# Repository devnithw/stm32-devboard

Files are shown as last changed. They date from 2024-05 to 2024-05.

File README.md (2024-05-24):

# STM32 Development board

This project contains KiCAD project files for a custom STM32 development board PCB which uses the STM32F103C8Tx microcontroller.

## Schematic design
The PCB schematic file for development board is contained in the file `stm32_board.kicad_sch`. The following is a screenshot of the schematic. 

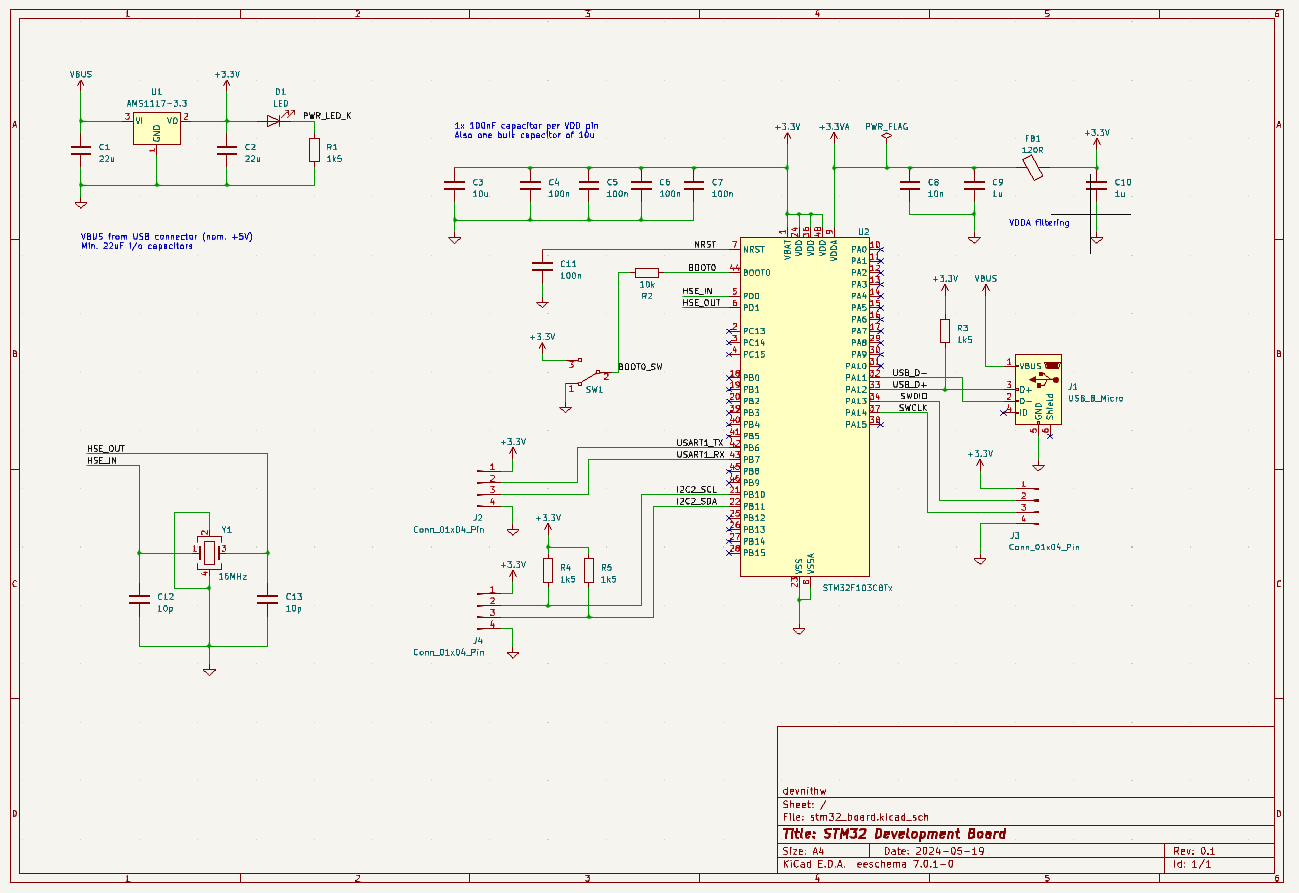
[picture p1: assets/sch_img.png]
Schematic


The development board uses the `STM32F103C8Tx` microcontroller. USB interface is used for both power supply and serial communication. The power fdrom the USB interface is regulated to +3.3V using the regulator circuit. An High Speed External clock is used for 16 MHz operation. The board includes pin header ports for UART and I2C communication also.

## PCB design
The PCB layout file for the circuit is contained in `stm32_board.kicad_pcb` file. Below is the screenshot of the final PCB layout after routing. I have included mounting holes for the board to be mounted onto a enclosure. The footprints for most of the components have been used from the KiCAD library itself. 3D view for the USB port was downloaded from the manufaturer's website as a step file. It is included in the file `629105150521 (rev1).stp`. I have added male headers for the UART, Serial Wire Debug and I2C communication ports. These can be configured using the STM32 Cube IDE software. 

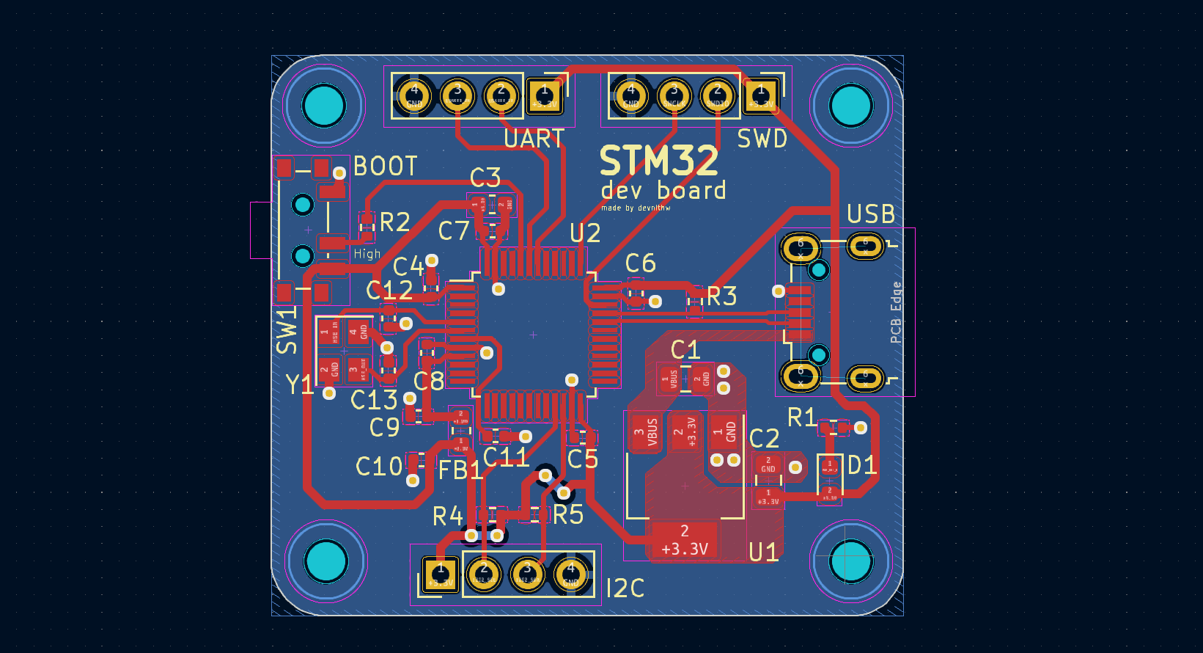
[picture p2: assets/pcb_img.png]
PCB


Shown below is the 3D view of the routed and finalized PCB.

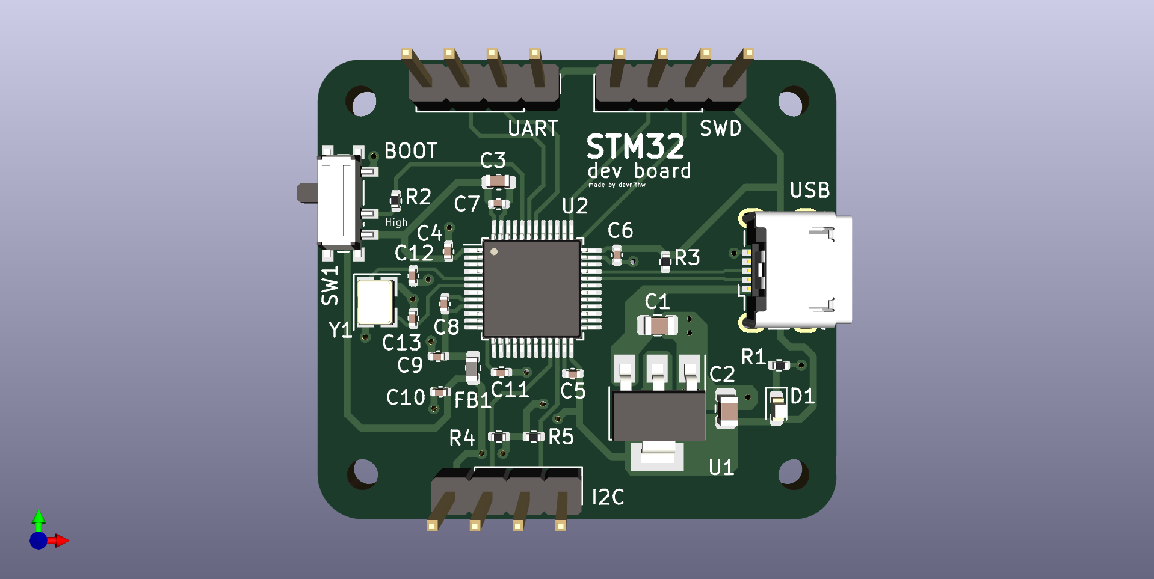
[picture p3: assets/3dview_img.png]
3DView


This project was done following the Udemy course by Philip Salmony. [Reference](https://www.udemy.com/course/learn-kicad-v6-and-stm32-hardware-design/)

## Technologies Used
- KiCAD V7
- STM32

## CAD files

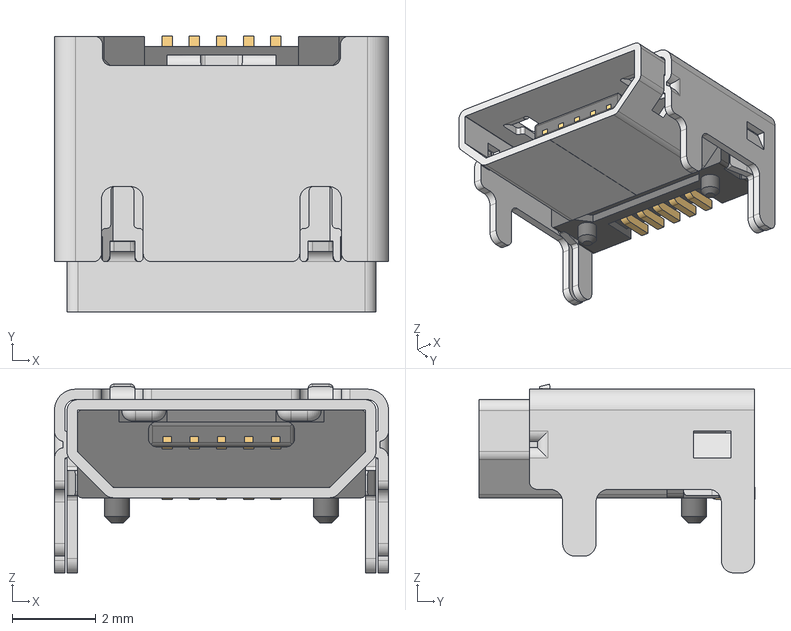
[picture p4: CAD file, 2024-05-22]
629105150521 (rev1).stp
8.00 x 6.60 x 4.52 mm
629105150521_Housing
629105150521_Pin1 x 4
629105150521_Pin2
629105150521_Shielding2
629105150521_Shielding

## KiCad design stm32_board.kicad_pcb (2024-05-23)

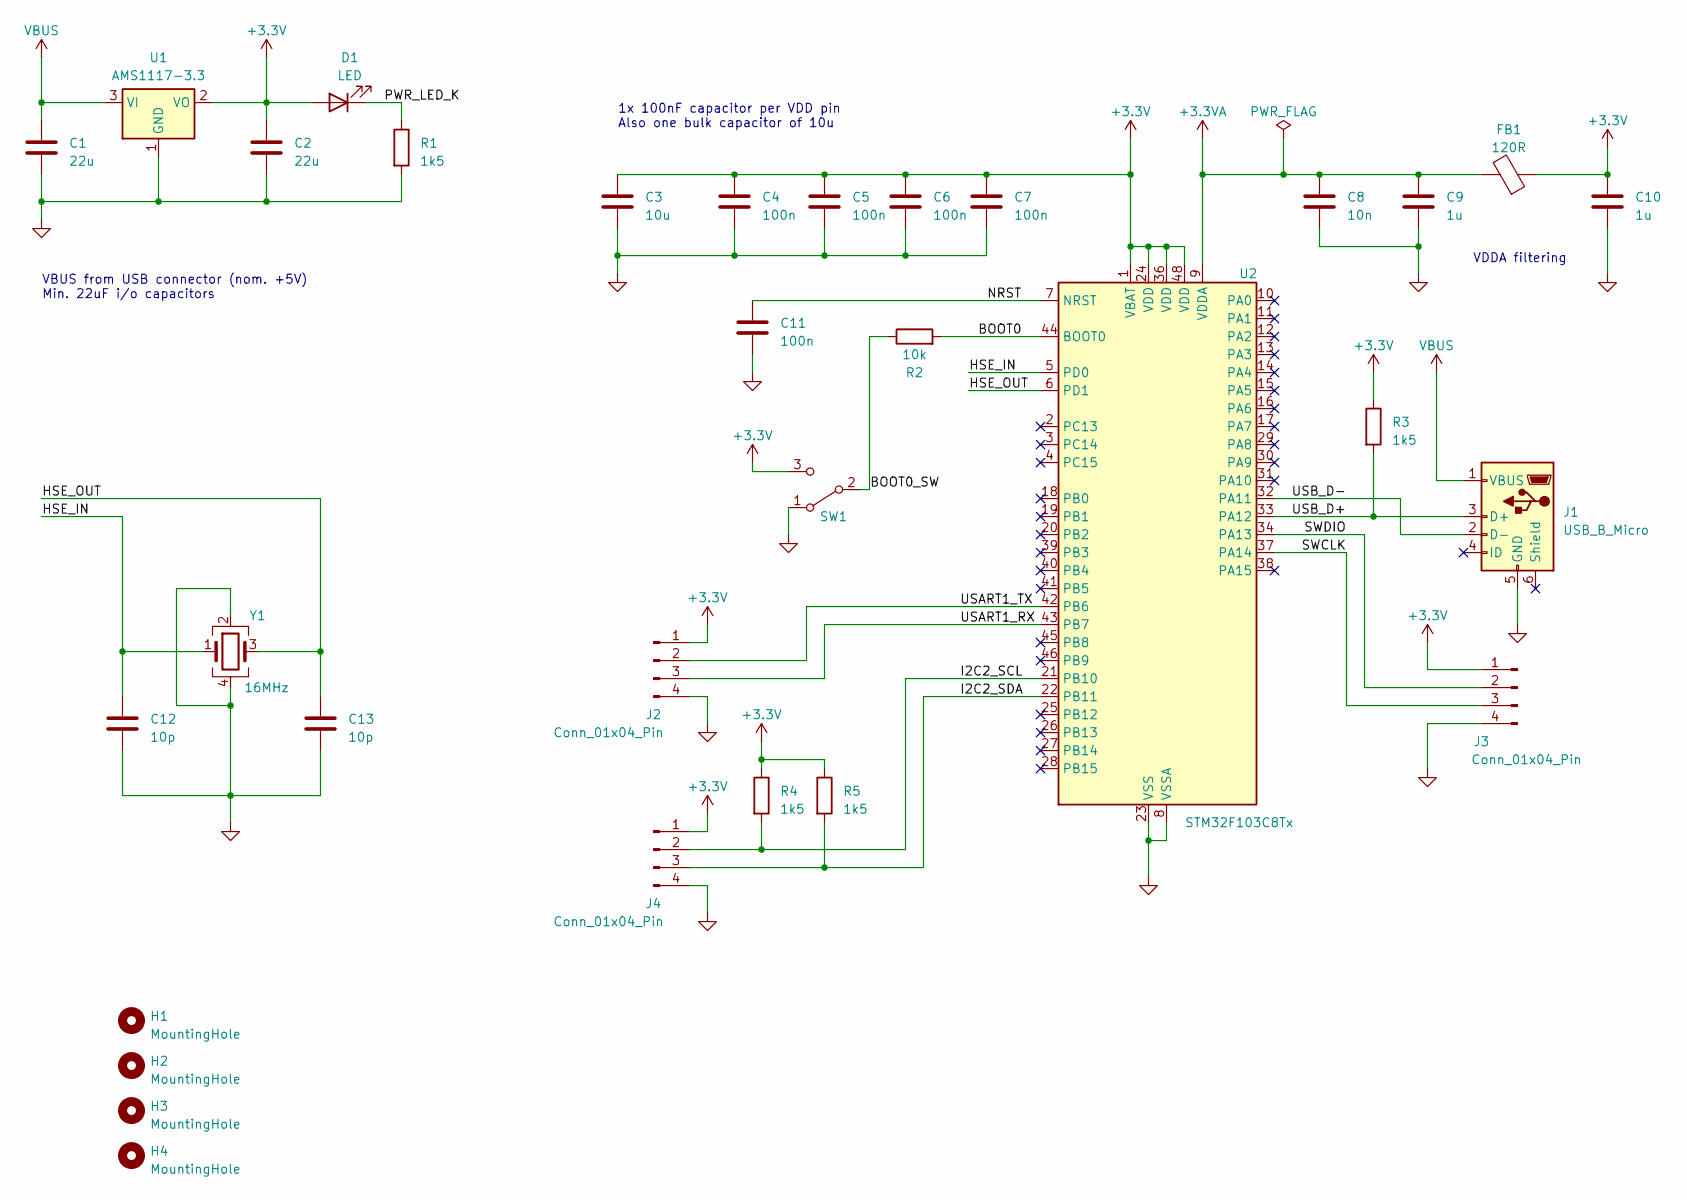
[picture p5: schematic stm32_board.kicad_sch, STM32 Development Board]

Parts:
C1, C2: 22u; C_0805_2012Metric
C3: 10u; C_0603_1608Metric
C4, C5, C6, C7, C11: 100n; C_0402_1005Metric
C8: 10n; C_0402_1005Metric
C9, C10: 1u; C_0402_1005Metric
C12, C13: 10p; C_0402_1005Metric
D1: LED; LED_0603_1608Metric
FB1: 120R; L_0603_1608Metric
H1, H2, H3, H4: MountingHole; MountingHole_2.2mm_M2
J1: USB_B_Micro; USB_Micro-B_Wuerth_629105150521
J2, J3, J4: Conn_01x04_Pin; PinHeader_1x04_P2.54mm_Vertical
R1, R3, R4, R5: 1k5; R_0402_1005Metric
R2: 10k; R_0402_1005Metric
SW1: SW_SPDT; SW_SPDT_PCM12
U1: AMS1117-3.3; SOT-223-3_TabPin2
U2: STM32F103C8Tx; LQFP-48_7x7mm_P0.5mm
Y1: 16MHz; Crystal_SMD_3225-4Pin_3.2x2.5mm

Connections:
+3.3V: C2.1, C3.1, C4.1, C5.1, C6.1, C7.1, C10.1, D1.2 (A), FB1.1, J2.1, J3.1, J4.1, R3.1, R4.1, R5.1, SW1.3 (C), U1.2 (VO), U2.1 (VBAT), U2.24 (VDD), U2.36 (VDD), U2.48 (VDD)
+3.3VA: C8.1, C9.1, FB1.2, U2.9 (VDDA)
/BOOT0: R2.2, U2.44 (BOOT0)
/BOOT0_SW: R2.1, SW1.2 (B)
/HSE_IN: C12.1, U2.5 (PD0), Y1.1
/HSE_OUT: C13.1, U2.6 (PD1), Y1.3
/I2C2_SCL: J4.2, R4.2, U2.21 (PB10)
/I2C2_SDA: J4.3, R5.2, U2.22 (PB11)
/NRST: C11.1, U2.7 (NRST)
/PWR_LED_K: D1.1 (K), R1.1
/SWCLK: J3.3, U2.37 (PA14)
/SWDIO: J3.2, U2.34 (PA13)
/USART1_RX: J2.3, U2.43 (PB7)
/USART1_TX: J2.2, U2.42 (PB6)
/USB_D+: J1.3 (D+), R3.2, U2.33 (PA12)
/USB_D-: J1.2 (D-), U2.32 (PA11)
GND: C1.2, C2.2, C3.2, C4.2, C5.2, C6.2, C7.2, C8.2, C9.2, C10.2, C11.2, C12.2, C13.2, J1.5 (GND), J2.4, J3.4, J4.4, R1.2, SW1.1 (A), U1.1 (GND), U2.8 (VSSA), U2.23 (VSS), U2.35 (VSS), U2.47 (VSS), Y1.2, Y1.4
VBUS: C1.1, J1.1 (VBUS), U1.3 (VI)

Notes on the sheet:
1x 100nF capacitor per VDD pin Also one bulk capacitor of 10u
VBUS from USB connector (nom. +5V) Min. 22uF i/o capacitors
VDDA filtering

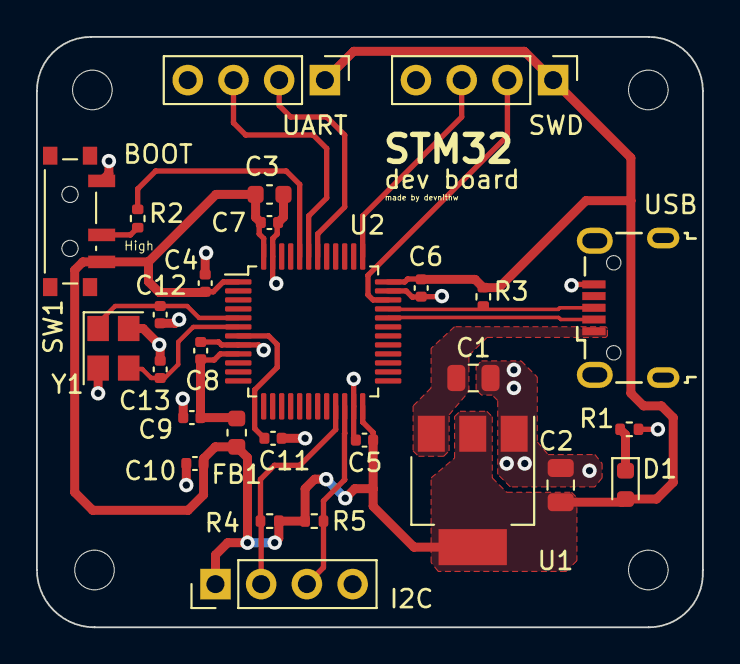
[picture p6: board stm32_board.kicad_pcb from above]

Board: 2 copper layers, 37.0 x 32.8 mm, 32 parts (0 on the bottom side), 18 nets.

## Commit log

2024-05-10 Added first project
    [attiny85_USB.kicad_pcb, attiny85_USB.kicad_sch]
2024-05-11 Added STM32 blue pill schematic
    [stm32_board.kicad_pcb, stm32_board.kicad_sch]
2024-05-12 Added Bootloader switch
    [stm32_board.kicad_sch]
2024-05-15 Removed other folders
    [attiny85_USB.kicad_pcb, attiny85_USB.kicad_sch]
2024-05-15 Updated folder structure
    [stm32_board.kicad_pcb, stm32_board.kicad_sch]
2024-05-15 Added Crystal Oscillator
    [stm32_board.kicad_sch]
2024-05-15 Added USB jack
    [stm32_board.kicad_sch]
2024-05-15 Added connectors
    [stm32_board.kicad_sch]
2024-05-19 Added notes + fixed annotations
    [stm32_board.kicad_sch]
2024-05-19 Added footprints
    [stm32_board.kicad_sch]
2024-05-19 Added image, updated README
    [stm32_board.kicad_sch]
2024-05-22 Updated PCB and added step file
    [629105150521 (rev1).stp, stm32_board.kicad_sch]
2024-05-22 Updated PCB
    [stm32_board.kicad_pcb]
2024-05-23 Finished PCB routing
    [stm32_board.kicad_pcb, stm32_board.kicad_sch]
